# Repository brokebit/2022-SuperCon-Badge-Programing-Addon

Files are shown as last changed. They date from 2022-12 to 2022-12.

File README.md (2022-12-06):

# 2022 SuperCon Badge USB Programing Add On Module
This project is an open-source hardware add-on that allows you to easily upload & download programs via USB and interact with the Input & Output pins via buttons and LEDs. It also passes all header pins through so you can daisy chain other add-ons. Input buttons, output LEDs, and USB UART can all be disabled via DIP switches. 

The board is a 6-layer design made in KiCad. The surface mount parts should be available directly from JLC PCB, and the through-hole parts are available via Digiki or your other favorite supplier. 

The 5V USB supply only powers the USB UART. 

## Through Hole Parts
- [12 Pin Femaile Header](https://www.digikey.com/en/products/detail/sullins-connector-solutions/PPTC121LGBN-RC/775906)
- [12 Pin Male Header](https://www.digikey.com/en/products/detail/adam-tech/PH1RA-12-UA/9830541)
- [4 Position SPST DIP Switch 2.54mm pitch](https://www.digikey.com/en/products/detail/grayhill-inc/76SB04T/726228)
- [2 Position SPST DIP Switch 2.54mm pitch](https://www.digikey.com/en/products/detail/grayhill-inc/76SB02ST/726171)
- [6mm Buttons](https://www.digikey.com/en/products/detail/te-connectivity-alcoswitch-switches/1825910-3/2400476)
## Features
- Passthrough header
- Four input buttons for input I/O pins
- Four output LEDs for output I/O pins
- CP210x USB Uart for serial I/O and upload/download programs
## Resources
- [Schematic](https://github.com/brokebit/2022-SuperCon-Badge-Programing-Addon/blob/main/Schematic-111222-v0.1.pdf?raw=true)
- [BOM file for PCB Manufacturer](https://github.com/brokebit/2022-SuperCon-Badge-Programing-Addon/blob/main/Manufacturing/BOM_ProgramingAddOn.xlsx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)
- [Position file for PCB Manufacturer](https://github.com/brokebit/2022-SuperCon-Badge-Programing-Addon/blob/main/Manufacturing/ProgramingAddOn-pos.xlsx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)
- [Gerber files for PCB Manufacturer](https://github.com/brokebit/2022-SuperCon-Badge-Programing-Addon/blob/main/Manufacturing/ProgramingAddOn.zip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)

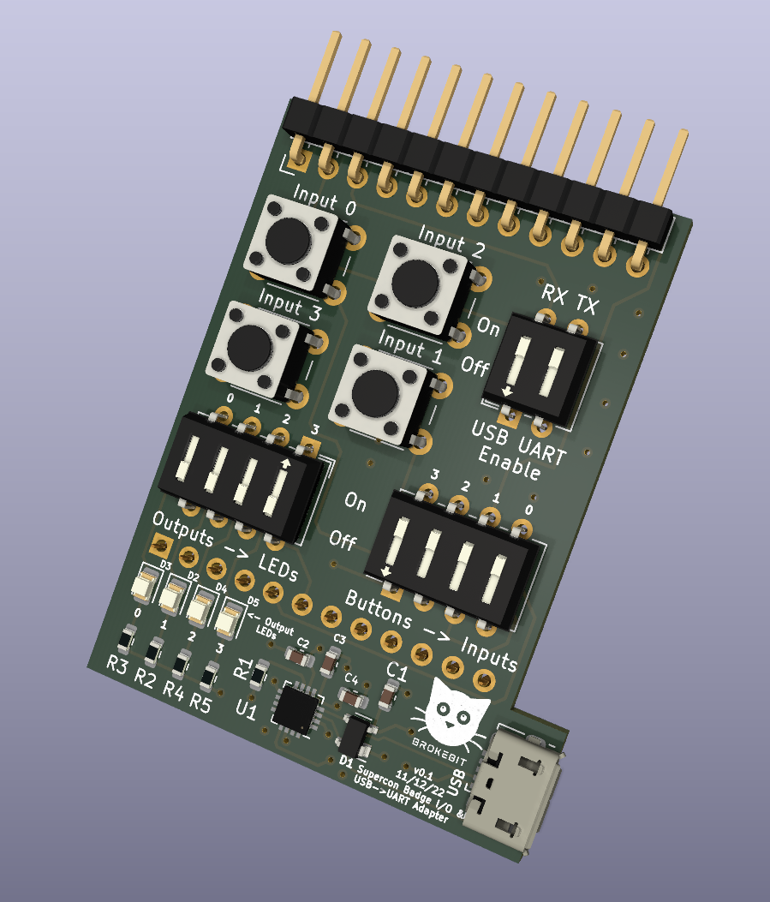
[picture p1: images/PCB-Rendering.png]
PCB Picture - Front
 
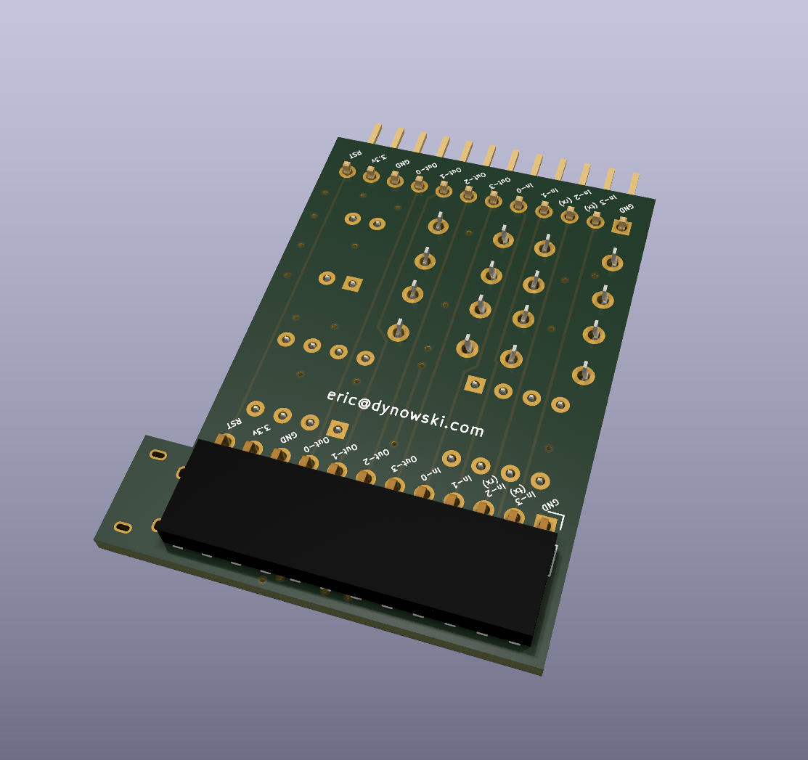
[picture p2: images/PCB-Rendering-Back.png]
PCB Picture - Back

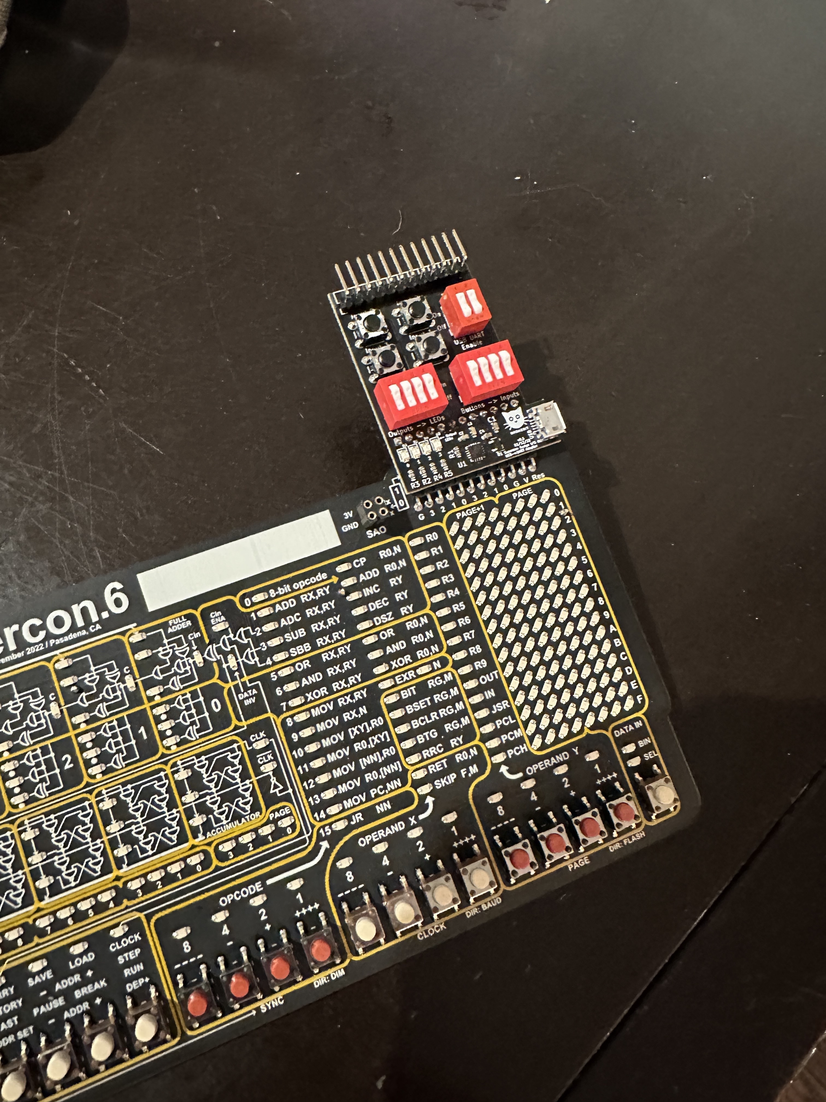
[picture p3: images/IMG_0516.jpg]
Picture, board plugged into badge


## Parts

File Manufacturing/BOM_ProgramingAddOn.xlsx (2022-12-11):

Ref | Qnty | Value | Cmp name | Footprint | Description | Vendor
C1, C4, | 2 | .1uf | C | Capacitor_SMD:C_0603_1608Metric | Unpolarized capacitor
C2, C3, | 2 | 4.7uf | C | Capacitor_SMD:C_0603_1608Metric | Unpolarized capacitor
D1, | 1 | SP0503BAHT | SP0503BAHT | Package_TO_SOT_SMD:SOT-143 | TVS Diode Array, 5.5V Standoff, 3 Channels, SOT-143 package
D2, D3, D4, D5, | 4 | 50 Ohms | LED | LED_SMD:LED_0805_2012Metric | Light emitting diode
J1, | 1 | USB_B_Micro | USB_B_Micro | Connector_USB:USB_Micro-B_Amphenol_10118194_Horizontal | USB Micro Type B connector
J4, | 1 | Conn_01x12_Male | Conn_01x12_Male | Connector_PinHeader_2.54mm:PinHeader_1x12_P2.54mm_Horizontal | Generic connector, single row, 01x12, script generated (kicad-library-utils/schlib/autogen/connector/)
J5, | 1 | Conn_01x12_Female | Conn_01x12_Female | Connector_PinHeader_2.54mm:PinHeader_1x12_P2.54mm_Horizontal | Generic connector, single row, 01x12, script generated (kicad-library-utils/schlib/autogen/connector/)
R1, | 1 | 1k | R_US | Resistor_SMD:R_0603_1608Metric | Resistor, US symbol
R2, R3, R4, R5, | 4 | R_US | R_US | Resistor_SMD:R_0603_1608Metric | Resistor, US symbol
SW1, | 1 | SW_DIP_x02 | SW_DIP_x02 | Button_Switch_THT:SW_DIP_SPSTx02_Slide_6.7x6.64mm_W7.62mm_P2.54mm_LowProfile | 2x DIP Switch, Single Pole Single Throw (SPST) switch, small symbol
SW2, SW3, SW4, SW6, | 4 | SW_Push | SW_Push | Button_Switch_THT:SW_PUSH_6mm | Push button switch, generic, two pins
SW5, SW7, | 2 | SW_DIP_x04 | SW_DIP_x04 | Button_Switch_THT:SW_DIP_SPSTx04_Slide_6.7x11.72mm_W7.62mm_P2.54mm_LowProfile | 4x DIP Switch, Single Pole Single Throw (SPST) switch, small symbol
U1, | 1 | CP2102N-Axx-xQFN20 | CP2102N-Axx-xQFN20 | Package_DFN_QFN:SiliconLabs_QFN-20-1EP_3x3mm_P0.5mm_EP1.8x1.8mm | USB to UART master bridge, QFN-20

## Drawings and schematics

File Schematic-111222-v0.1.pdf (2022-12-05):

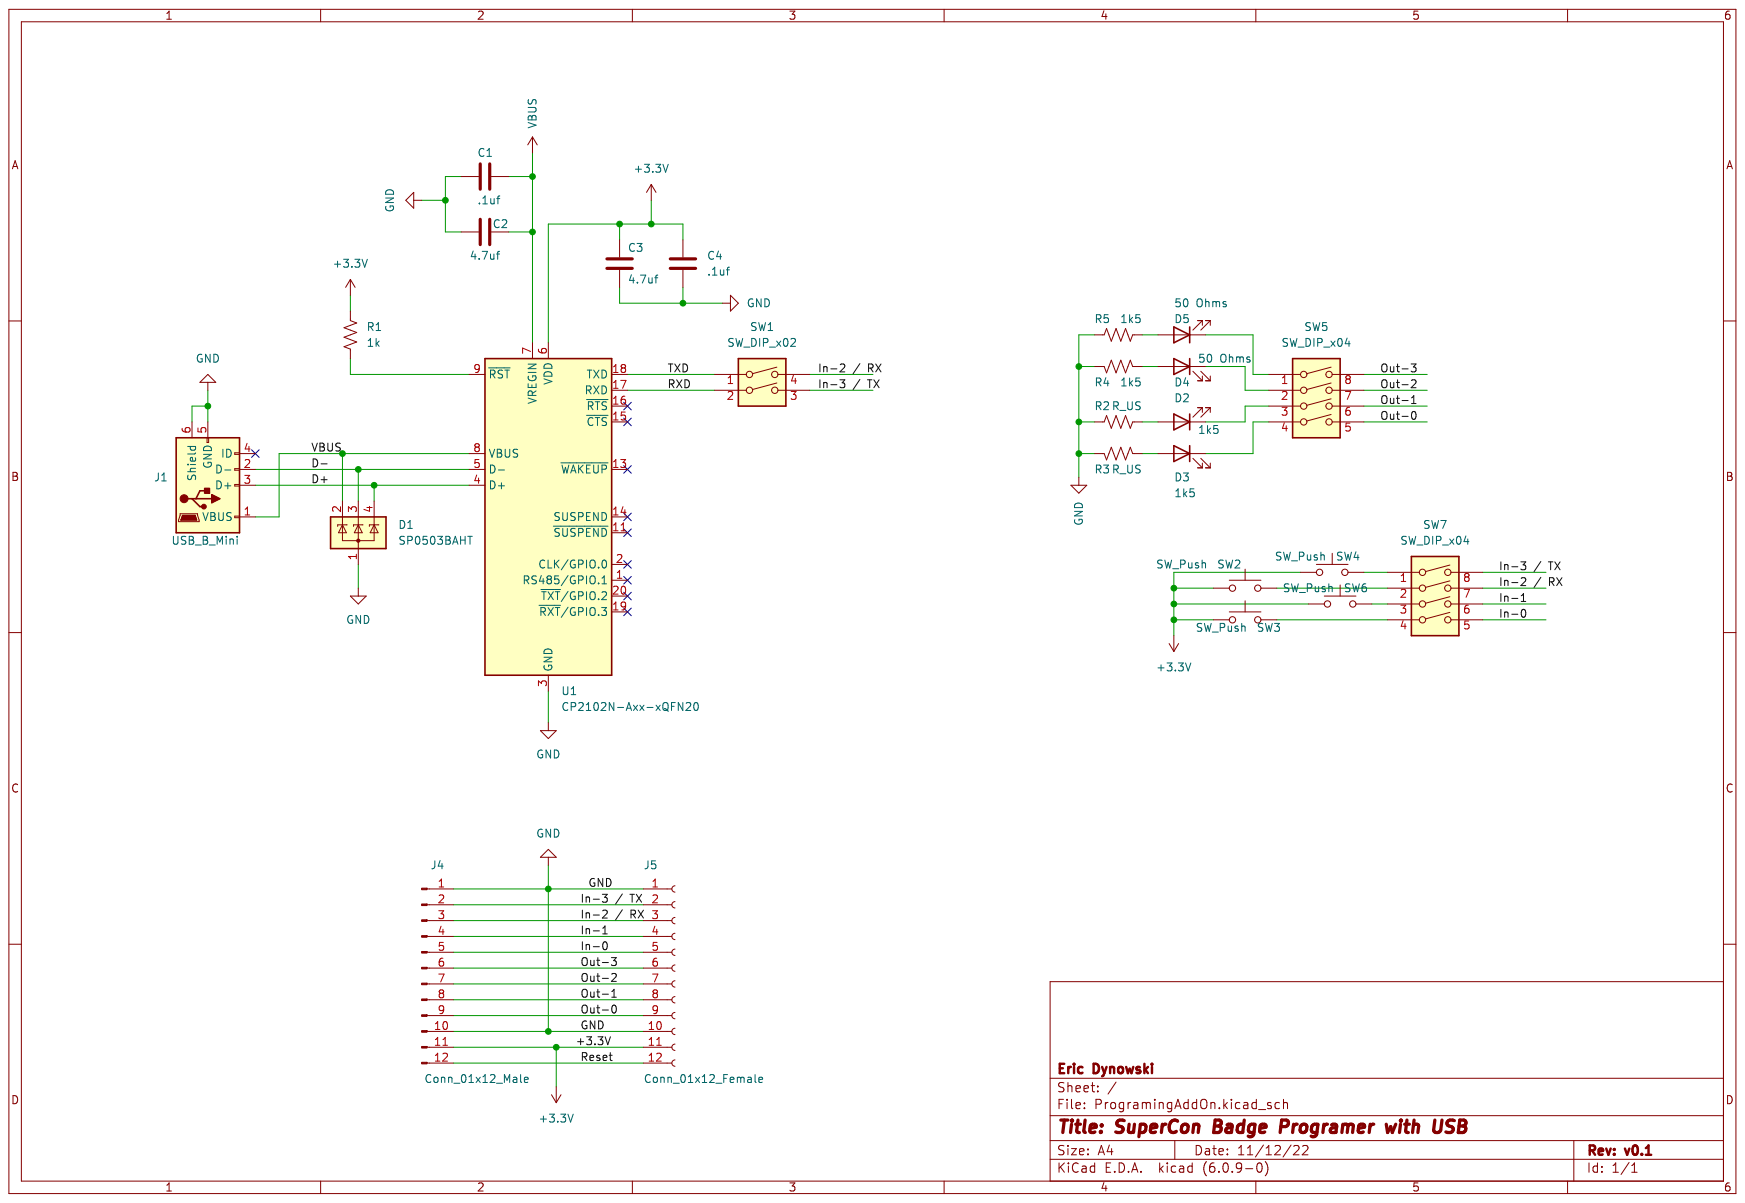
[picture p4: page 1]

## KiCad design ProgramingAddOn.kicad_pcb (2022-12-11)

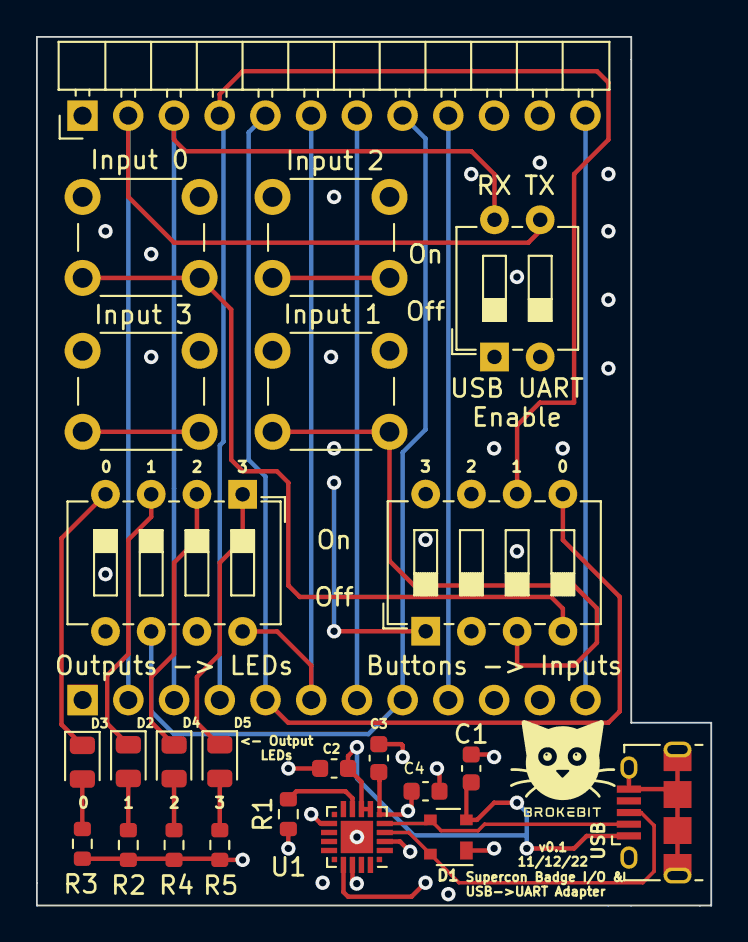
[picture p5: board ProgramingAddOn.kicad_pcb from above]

Board: 6 copper layers, 37.5 x 48.3 mm, 25 parts (1 on the bottom side), 29 nets.

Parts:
C1, C2, C3, C4: C; C_0603_1608Metric
D1: SP0503BAHT; SOT-143
D2, D3, D4, D5: LED; LED_0805_2012Metric
J1: USB_B_Micro; USB_Micro-B_Amphenol_10118194_Horizontal
J4: Conn_01x12_Male; PinHeader_1x12_P2.54mm_Horizontal
J5: Conn_01x12_Female; PinHeader_1x12_P2.54mm_Horizontal
R1, R2, R3, R4, R5: R_US; R_0603_1608Metric
SW1: SW_DIP_x02; SW_DIP_SPSTx02_Slide_6.7x6.64mm_W7.62mm_P2.54mm_LowProfile
SW2, SW3, SW4, SW6: SW_Push; SW_PUSH_6mm
SW5, SW7: SW_DIP_x04; SW_DIP_SPSTx04_Slide_6.7x11.72mm_W7.62mm_P2.54mm_LowProfile
U1: CP2102N-Axx-xQFN20; SiliconLabs_QFN-20-1EP_3x3mm_P0.5mm_EP1.8x1.8mm

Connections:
+3.3V: C3.1, C4.1, J4.11, J5.11, R1.1, SW2.1, SW3.1, SW4.1, SW6.1, U1.6 (VDD)
/D+: D1.4 (K), J1.3 (D+), U1.4 (D+)
/D-: D1.3 (K), J1.2 (D-), U1.5 (D-)
/In-0: J4.5, J5.5, SW7.5
/In-1: J4.4, J5.4, SW7.6
/In-2 / RX: J4.3, J5.3, SW1.4, SW7.7
/In-3 / TX: J4.2, J5.2, SW1.3, SW7.8
/Out-0: J4.9, J5.9, SW5.5
/Out-1: J4.8, J5.8, SW5.6
/Out-2: J4.7, J5.7, SW5.7
/Out-3: J4.6, J5.6, SW5.8
/RXD: SW1.2, U1.17 (RXD)
/Reset: J4.12, J5.12
/TXD: SW1.1, U1.18 (TXD)
GND: C1.2, C2.2, C3.2, C4.2, D1.1 (A), J1.5 (GND), J1.6 (Shield), J4.1, J4.10, J5.1, J5.10, R2.1, R3.1, R4.1, R5.1, U1.3 (GND), U1.12 (GND), U1.21 (GND)
unnamed: D2.1 (K), SW5.3
unnamed: D2.2 (A), R2.2
unnamed: D3.1 (K), SW5.4
unnamed: D3.2 (A), R3.2
unnamed: D4.1 (K), SW5.2
unnamed: D4.2 (A), R4.2
unnamed: D5.1 (K), SW5.1
unnamed: D5.2 (A), R5.2
unnamed: R1.2, U1.9 (~RST)
unnamed: SW2.2, SW7.2
unnamed: SW3.2, SW7.4
unnamed: SW4.2, SW7.1
unnamed: SW6.2, SW7.3
VBUS: C1.1, C2.1, D1.2 (K), J1.1 (VBUS), U1.7 (VREGIN), U1.8 (VBUS)

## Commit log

2022-12-05 Add schematic PDF and PCB rendering
    [ProgramingAddOn.kicad_sch]
2022-12-05 Add image of actual device on badge
2022-12-11 Update part descriptions. Change USB mini to micro.
    [BOM_ProgramingAddOn.xlsx, ProgramingAddOn.kicad_pcb, ProgramingAddOn.kicad_sch]
